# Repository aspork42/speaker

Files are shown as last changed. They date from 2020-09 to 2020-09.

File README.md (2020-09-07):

# Smart Speaker
Smart Speaker for DIY Home Automation 

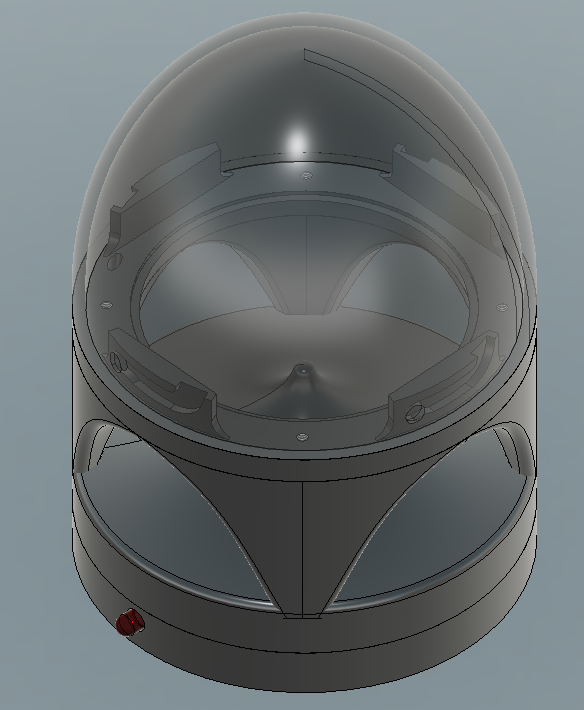
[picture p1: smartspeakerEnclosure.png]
Smart Speaker Enclosure


This is based on software by Mr DIY's "Notifier" project. I have modified it to include a status LED and created a PCB and enclosure for a 3" speaker.

This can be used to play a sound when doors are opened, faucets are left running, water is found flooding the basement or to play nursery rhymes in the kids room at night.

This uses a D1 Mini WIFI module, an Adafruit MAX 98357A I2S Audio DAC & amplifier, and a custom PCB.

Most of the base software is from Mr. DIY and all the write-ups can be found on his GitLab page: https://gitlab.com/MrDIYca/mrdiy-audio-notifier

STP files are located on Thingiverse: https://www.thingiverse.com/thing:4590242

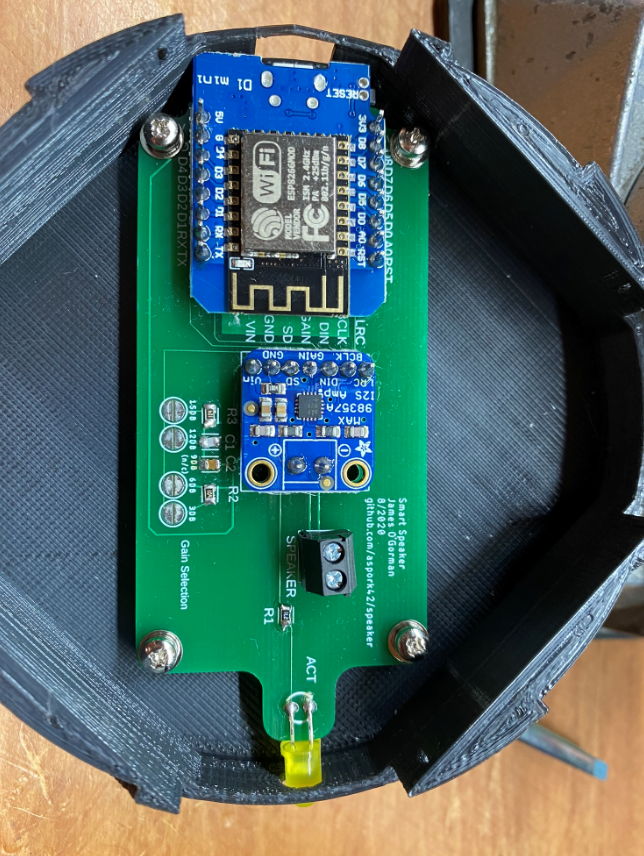
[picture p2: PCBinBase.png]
PCB mounted inside base unit


Finished product:
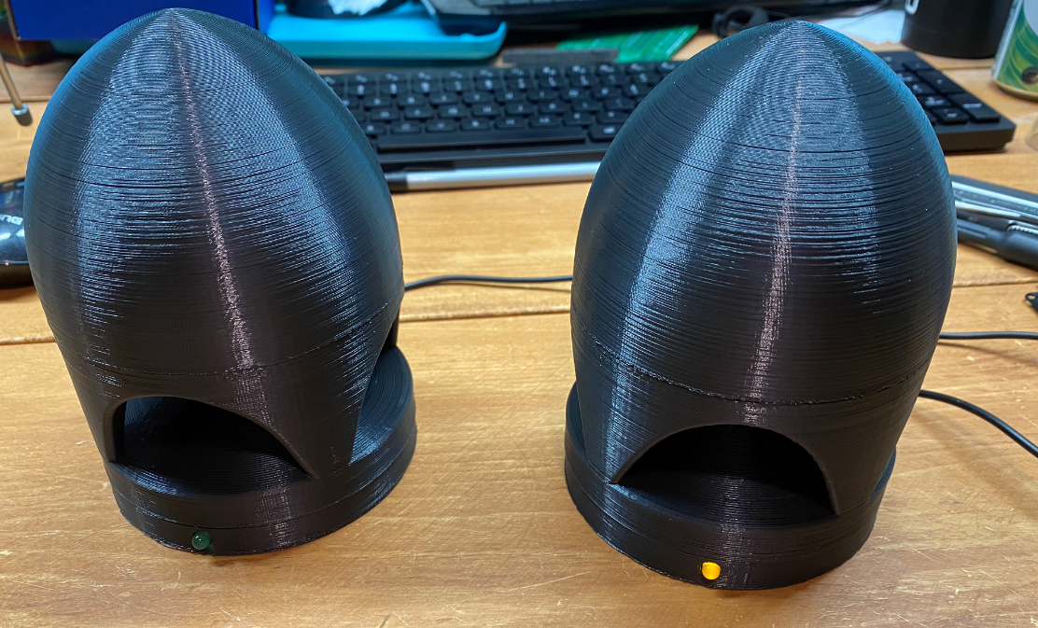
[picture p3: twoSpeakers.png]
Two finsihed units


Speaker:https://www.adafruit.com/product/1314

I2S DAC/Amplifier: https://www.adafruit.com/product/3006

PCB can be ordered from the Gerbers attached in the zip file.

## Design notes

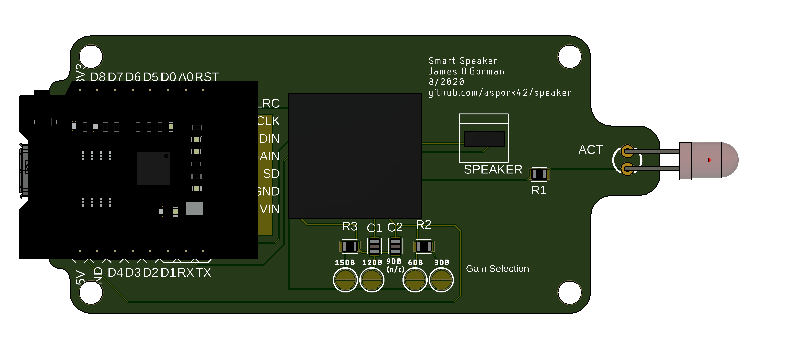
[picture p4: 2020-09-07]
PCB.png

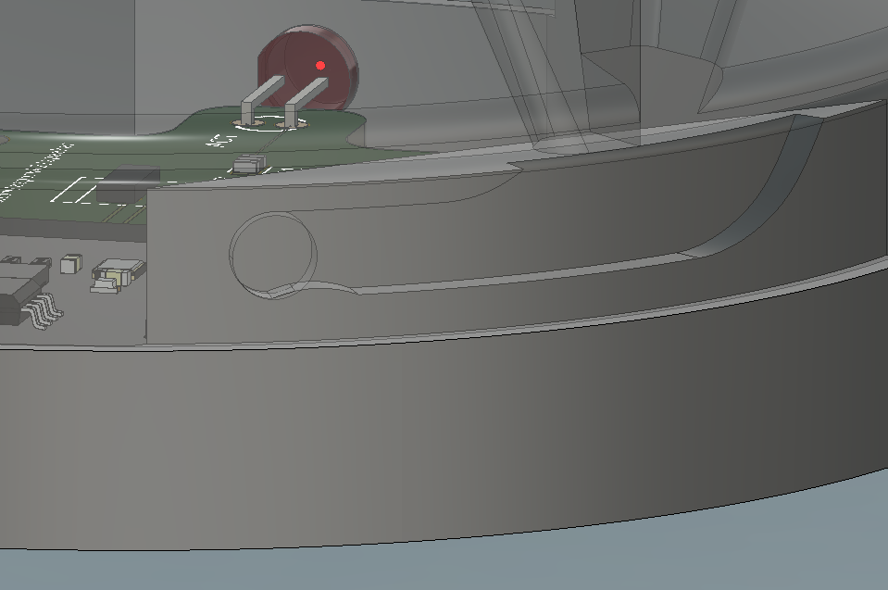
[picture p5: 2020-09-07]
CenterAndBaseInterlock.png

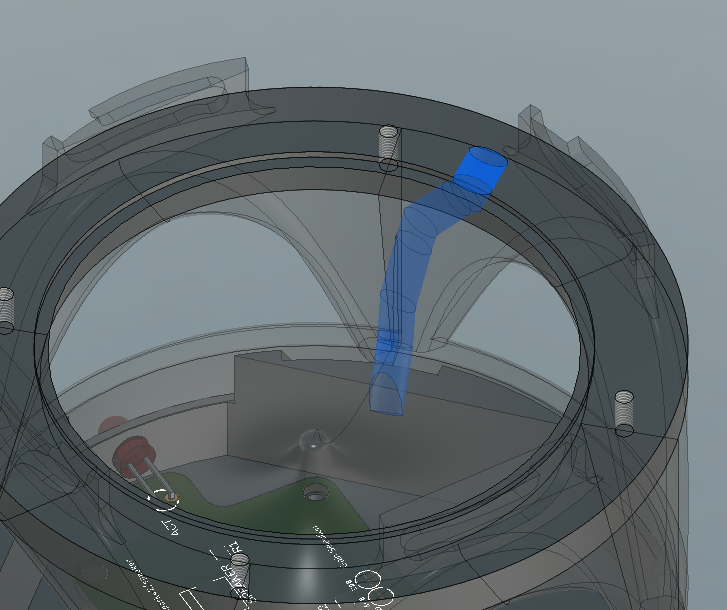
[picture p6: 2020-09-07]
WireChannel.png

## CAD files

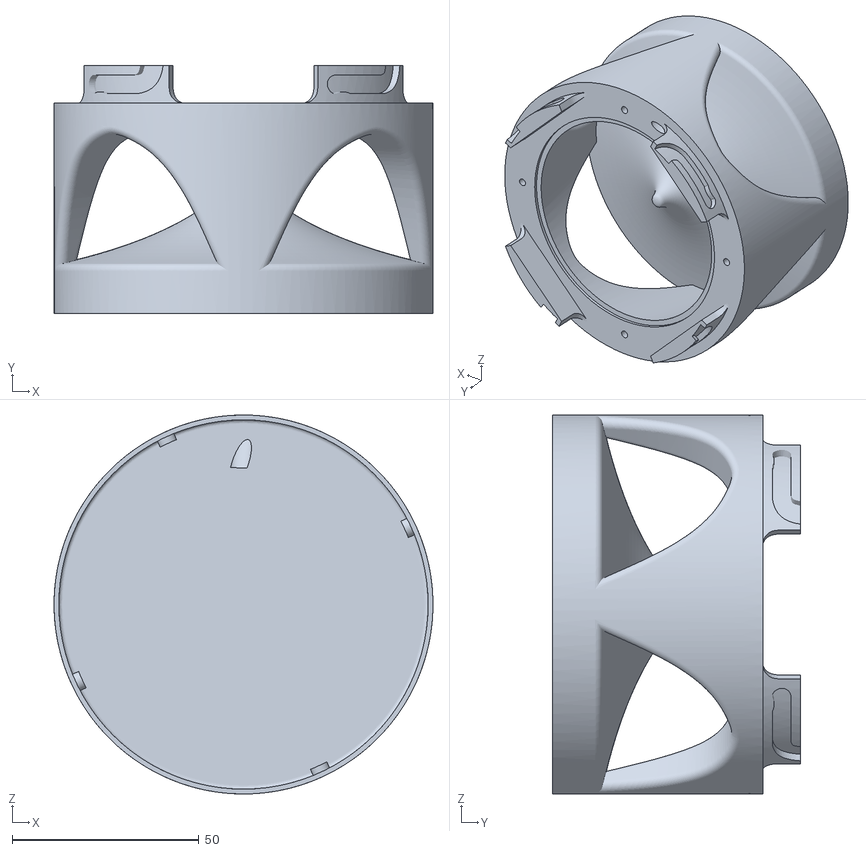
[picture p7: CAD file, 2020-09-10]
MainBody-1.stl
101.6 x 66.4 x 101.6

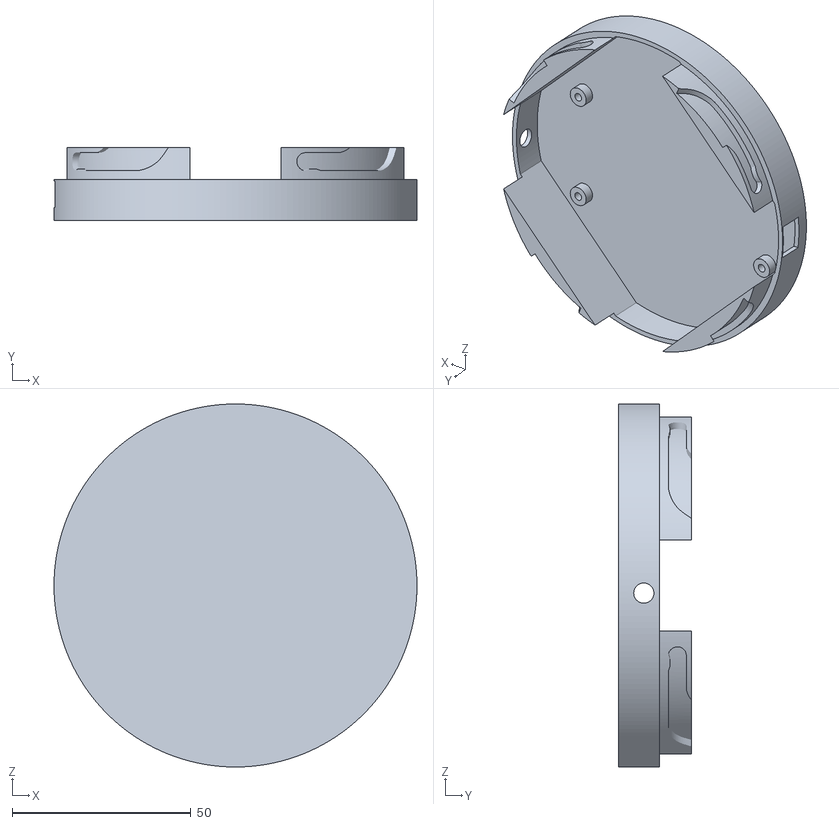
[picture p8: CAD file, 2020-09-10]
Base-1.stl
101.6 x 20.5 x 101.6

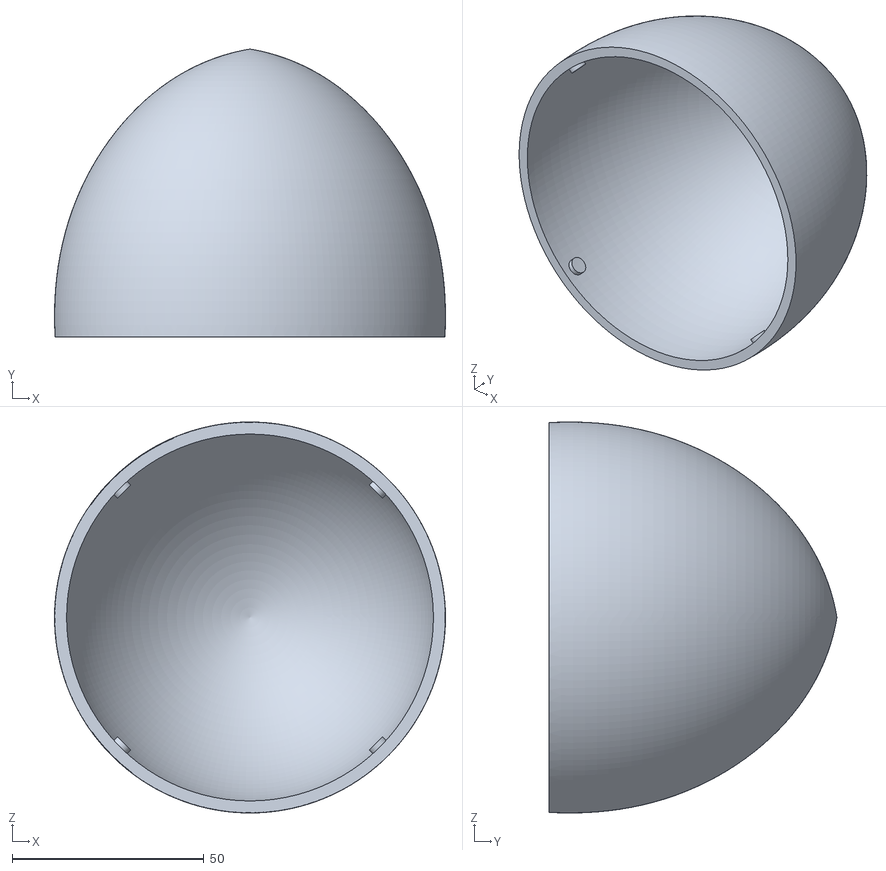
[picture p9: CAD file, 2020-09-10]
Top.stl
101.9 x 75.0 x 101.9

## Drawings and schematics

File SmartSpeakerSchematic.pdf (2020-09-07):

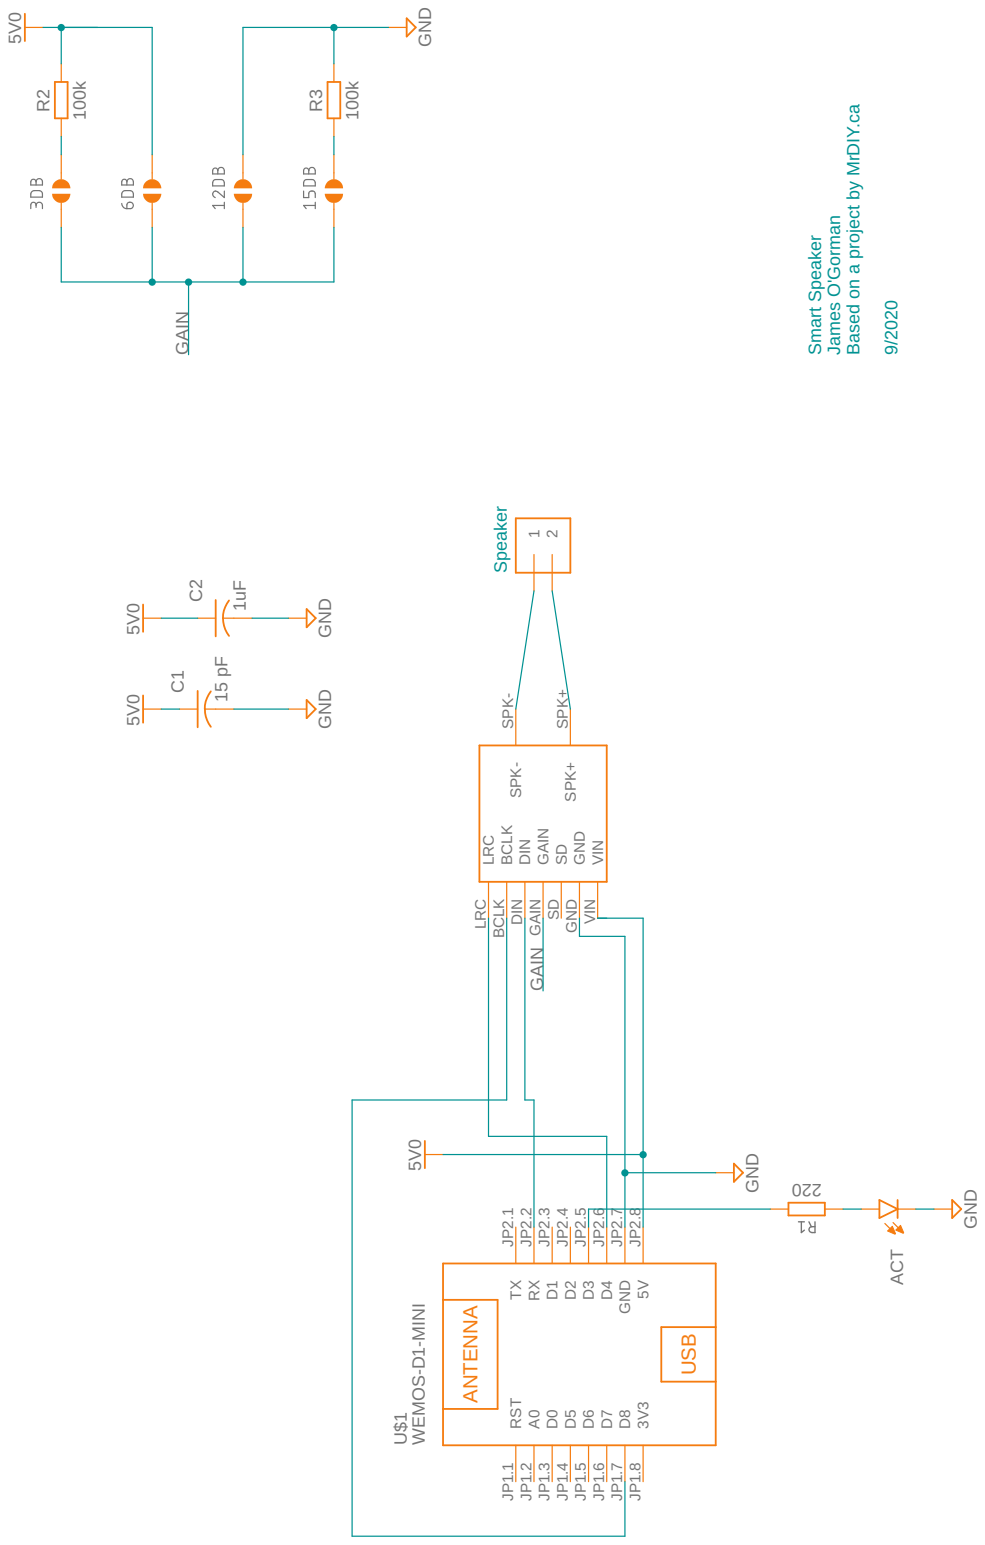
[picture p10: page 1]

WEMOS-D1-MINI GNDGN5VD 0 GND 5V0 5V0 GN1D5 pF 5V0 GN1DuF RST JP1.1 A0 JP1.2 D0 JP1.3 D5 JP1.4 D6 JP1.5 D7 JP1.6 D8 JP1.7 3V3 JP1.8 TX JP2.1 RX JP2.2 D1 JP2.3 D2 JP2.4 D3 JP2.5 D4 JP2.6 GND JP2.7 5V JP2.8 U$1 ACT 022 R2 100k R3 100k SPK- SPK- SPK+ SPK+ VIN VIN GND GND SD SD GAIN GAIN BCLK BCLK LRC LRC DIN DIN C1 12 C2 GAIN GAIN USB ANTENNA Speaker Smart Speaker James O'Gorman Based on a project by MrDIY.ca 9/2020

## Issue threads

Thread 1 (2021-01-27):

DAC Query

adamrhoades, 2021-01-27:
Love this project, perfect solution for offline alerts at my elderly mothers house.

I’m attempting to solve the popping issue and plan to try a  I2S DAC.

My question… I’m using an old set of amplified PC speakers as the output, would the adafruit MAX98357A still be a suitable DAC, or would an un-amplfied one such as the UDA1334A be a better fit for my use case?

Thanks in advance!

aspork42, 2021-01-27:
Technically you are correct. The component that I used includes an amplifier, so you could plug a speaker in directly to it. If you are using an external amp like an old set of PC speakers, then you can use the UDA1334A. That being said, you could just as well still use the project as posted and control the volume/gain via the solder jumpers on the PCB to run it down in amplification and then the PC speakers will still work just fine. If you're not using the PCB posted here, then i'd go the route you selected. You can use perfboard and solder the components. and I'm like >95% sure that it should work as-is.

adamrhoades, 2021-01-28:
Thank you so much, I'll order a UDA1334A and see how I get on. Will keep you posted!

adamrhoades, 2021-01-29:
Got the UDA1334A wired up and the esp8266_mrdiy_mqtt_local_notifier-I2S.bin flashed.

Partial Success, once configured it plays the guitar riff to indicate it has connected to the wifi and the MQTT.

The module returns pings and is accessible via the web interface, but it will not respond to MQTT messages.

Power cycling makes it forget the wifi settings and it goes into AP mode.

Any suggestions for me to troubleshoot?

aspork42, 2021-01-29:
Try to see if you can compile and upload from the Arduino IDE. I had the same problem with the original Mr DIY image until I did that. Otherwise check settings for erasing flash.

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

adamrhoades, 2021-02-03:
Thanks for getting back to me.

I complied it myself, erased the flash and uploaded and that has solved the issue of forgetting wifi.

The DAC seems to be working as it plays the guitar riff on connection. I assume that also means it has connected to the MQTT broker?

However it will still not respond to MQTT commands.

Any further thoughts?

aspork42, 2021-02-04:
Sorry for the troubles. It is probably related to posting to the correct MQTT Topic. The sound should only play if the device connects to the broker; so that part should be fine. I’ll post the topics i’m using to you in a little while when I get a second. Don’t forget that you can configure the topic individually for each device. I have 5, so each has its own sub-topic that it listens to. That’s why the documentation says "mqttFullTopic()/play"

It doesn’t mean to POST to mqttFullTopic/Play, it means that once you configure your topic like “MySpeaker” that you can then post to MySpeaker/play and it will respond.

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

aspork42, 2021-02-04:
This is my config website:
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

and I post to the full topic like this:
Notifier/Basement/say
Notifier/Basement/play
Notifier/Basement/tone
Notifier/Basement/stop
Notifier/Basement/volume

and get LWT from:
Notifier/Basement/LWT

aspork42, 2021-02-04:
What part of the world are you in?

adamrhoades, 2021-02-10:
So sorry for the late response... crazy week.

I'm based in Lincoln, England... you?

Adding the prefix of Notifier to my existing topic solved the problem
I'm now using: Notifier/Speakers

Initially I had problems with inconsistent playback quality; popping, missing portions etc but I reduced the MP3 files down to mono with a low variable bitrate of between 40-85kbps and it sounds great now!

I also experimented with copying the google tts cache mp3s and using those... they sound great too!

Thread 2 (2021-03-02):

Board Conversion

creativewitty, 2021-03-02:
Hey James, MrDiy directed to me to this fork and this looks great.
I know a bit about electronics but not as much..

Is there a way to convert the board to components where normal non smd components are required.
and say if i wanted to add a poteniometer for volume where would that be implemented?

aspork42, 2021-03-02:
Hello,

Version 2 of the PCB which is on GitHub has been converted with 'dual pattern' so you can use through-hole resistors (OR surface mount). For the other components like the capacitors, you don't actually need to use them so you can leave unpopulated. They pre-set the amplification on the DAC.

If you wanted to add an analog volume knob, you would use a potentiometer. Hook one side to 3.3v, the opposite side to GND, and the center pin (which is the analog outputs) into the "A0" pin which is the analog. You would need to update the code to read the pin, look for a change in the analog value, and update the volume setting.

Reading an analog pin on the arduino (This will basically follow the Aruduino reference using pin A0)
https://www.arduino.cc/reference/en/language/functions/analog-io/analogread/

More info on reading an analog pin, along with diagram (on Arduino Uno) on how to wire it).
https://microcontrollerslab.com/analogread-arduino-example/

You would probably do something like the Map() function to map the 0-1028 analog value into a 0-100 for the volume and that will constrain the values to 0-100, and scaled accordingly.

creativewitty, 2021-03-03:
Wow This is great and thank you for your guidance, I should be getting my DACs in the mail today so will start to tinker with em and update my progress.

And For volume I realized MrDiy's code has volume commands too, so maybe I can just use something to control it via mqtt than hardware. but I will still try to achieve the volume option with the analog input. And will post my progress.

Cheers Aktion!

aspork42, 2021-03-03:
Sorry -  I guess I assumed you wanted to override the volume coming from MQTT. I've found that I don't change the volume on these. I run OpenHAB and use a rule to set the volume there on each device when they come online (by watching the LWT topic). I made five of these and put them around my house and LOVE having them.

So you could do the analog with a knob, or you could also do it with two buttons - UP and DOWN - which would be easier to code. When the button is pressed, you just run the volume up by 10 or down by 10.

creativewitty, 2021-03-03:
No I did, i did initially think of overriding that but since I will be using the speakers for alarm too i figured might not be a good idea to have a volume control on it :)

I am using home assistant and it's super easy with the mqtt integration so I will setup something for volume control from within.

I tested the system with a Drok amp and D1 chip and it works like a charm.
now time to optimize the setup using the Dac.
!

[first try](https://user-images.githubusercontent.com/1167235/109852438-c58cbf80-7c22-11eb-9cbd-760fd9f684a6.jpeg)

https://user-images.githubusercontent.com/1167235/109852443-c7568300-7c22-11eb-8278-7aabfb7b2606.mp4

aspork42, 2021-03-03:
Nice work! You could have the knob just override the current MQTT value, then have a rule reset the volume in the morning before the alarm goes off.

creativewitty, 2021-03-03:
Thanks, also wanted to ask you before you used the dac as a solution did you think of anything else to remove the pooping of clicking sound?

creativewitty, 2021-03-04:
Does this look right to you? I decided to go for dip switches for gain points.

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

aspork42, 2021-03-06:
I did play with it a little to try resolving the Pop, and finally just spent a few bucks on the DAC. The problem is using the Rx pin. The D1 mini writes it LOW (0 volts) when not playing audio, then writes it HIGH (3.3V) before playback starts. This is the cause for the pop. The analog audio level is millivolts peak to peak, so a 3+V change is a pretty large swing.

creativewitty, 2021-03-07:
Yeah I found the same info on the Interwebs :) But again thank you for taking out time to helping me, Your schematic was really helpful for me. I designed my first pcb. It is just a diff design with dip switches and thru mount resistor slot. very excited.

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

aspork42, 2021-03-07:
If you haven't ordered you PCB yet, don't forget to add mounting holes. Nice work on your first board!

creativewitty, 2021-03-07:
Thank you!! and yeah I left them out on purpose for this one.
But I might make another to put it our for people and there i will have the mounting holes.

I might even make a video about mqtt and home assistant where i will include this so will definitely leave your link there!

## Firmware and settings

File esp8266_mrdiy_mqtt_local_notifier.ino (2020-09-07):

/*  ==============================================================================================================
    MrDIY is an locally-controlled over MQTT, internet-independent media notifier that can play MP3s, stream
    icecast radios, read text and play RTTTL ringtones without any external components.

    Connect your audio jack to Rx and GND - an external amplifier if required. You can build a simple amp
    with a single 1kΩ resistor and an NPN 2N3904 transistor, like this:


                                        2N3904 (NPN)
                                       +---------+
                                       |         |     +--|
                                       | E  B  C |    / S |
                                       +-|--|--|-+    | P |
                                         |  |  +------+ E |
                                         |  |         | A |
           ESP8266-GND ------------------+  |  +------+ K |
                                            |  |      | E |
           ESP8266-I2SOUT (Rx) -----/\/\/\--+  |      \ R |
                                     1kΩ       |       +--|
           USB 5V -----------------------------+


    Commands, to:

     - Play MP3              MQTT topic: "mqttFullTopic()/play"
                             MQTT load: http://url-to-the-mp3-file/file.mp3

     - Play Icecast Stream   MQTT topic: "mqttFullTopic()/stream"
                             MQTT load: http://url-to-the-icecast-stream/file.mp3, example: http://22203.live.streamtheworld.com/WHTAFM.mp3

     - Play Ringtone         MQTT topic: "mqttFullTopic()/tone"
                             MQTT load: RTTTL formated text, example: Soap:d=8,o=5,b=125:g,a,c6,p,a,4c6,4p,a,g,e,c,4p,4g,a

     - Say Text              MQTT topic: "mqttFullTopic()/say"
                             MQTT load: Text to be read, example: Hello There. How. Are. You?

     - Change Volume         MQTT topic: "mqttFullTopic()/volume"
                             MQTT load: a double between 0.00 and 1.00, example: 0.7

     - Stop Playing         MQTT topic: "mqttFullTopic()/stop"

     To get status:

     - The notifier sends status update on this MQTT topic: "mqttFullTopic()/status"

                  "playing"       either paying an mp3, streaming, playing a ringtone or saying a text
                  "idle"          waiting for a command
                  "error"         error when receiving a command: example: MP3 file URL can't be loaded
                  "connected"     device just connected to MQTT server

     - The notifier plays a 2 second audio clip when it is first booted and connected to Wifi & MQTT


    To Upload to Wesmo D1 Mini:

     - Set CPU Frequency to 160MHz
     - Set IwIP to V2 Higher Bandwidth
     - Update the SSID info
     - Connect Rx to an AMP

    Dependencies:

     - ESP8266          https://github.com/esp8266/Arduino
     - ESP8266Audio     https://github.com/earlephilhower/ESP8266Audio
     - ESP8266SAM       https://github.com/earlephilhower/ESP8266SAM
     - IotWebConf       https://github.com/prampec/IotWebConf
     - PubSubClient     https://github.com/knolleary/pubsubclient


    Many thanks to all the authors and contributors to the above libraries - you have done an amazing job!

    For more info visit me at MrDIY.ca and find the Notifier Video on my YouTube channel:
    https://youtu.be/SPa9SMyPU58

  ============================================================================================================== */

//#define DEBUG_FLAG

#define USE_I2S //uncomment to use I2S DAC instead of Serial Rx pin.

#include "Arduino.h"
#include "boot_sound.h"
#include "ESP8266WiFi.h"
#include "PubSubClient.h"
#include "AudioFileSourceHTTPStream.h"
#include "AudioFileSourceICYStream.h"
#include "AudioFileSourcePROGMEM.h"
#include "AudioFileSourceBuffer.h"
#include "AudioGeneratorMP3.h"
#include "AudioGeneratorWAV.h"
#include "AudioGeneratorRTTTL.h"

#ifdef USE_I2S
  #include "AudioOutputI2S.h"
#else
  #include "AudioOutputI2SNoDAC.h"
#endif

#include "ESP8266SAM.h"
#include "IotWebConf.h"

AudioGeneratorMP3         *mp3 = NULL;
AudioGeneratorWAV         *wav = NULL;
AudioGeneratorRTTTL       *rtttl = NULL;
AudioFileSourceHTTPStream *file_http = NULL;
AudioFileSourcePROGMEM    *file_progmem = NULL;
AudioFileSourceICYStream *file_icy = NULL;
AudioFileSourceBuffer     *buff = NULL;

#ifdef USE_I2S
  AudioOutputI2S       *out = NULL;
#else
  AudioOutputI2SNoDAC       *out = NULL;
#endif

WiFiClient                wifiClient;
PubSubClient              mqttClient(wifiClient);
#define  port             1883
#define  MQTT_MSG_SIZE    256

#define LED_Pin 0 // for the external LED pin.

// AudioRelated ---------------------------
float volume_level              = 0.8;
String playing_status;
const int preallocateBufferSize = 2048;
void *preallocateBuffer         = NULL;
byte i;

//Get chip ID to append to ThingName to make unique
#ifdef ESP8266
String ChipId = String(ESP.getChipId(), HEX);
#elif ESP32
String ChipId = String((uint32_t)ESP.getEfuseMac(), HEX);
#endif

// WifiManager -----------------------------
String thingName = String("MrDIY Notifier - ") + ChipId; 
#define wifiInitialApPassword "mrdiy.ca"
char mqttServer[16];
char mqttUserName[32];
char mqttUserPassword[32];
char mqttTopicPrefix[32];
char mqttTopic[MQTT_MSG_SIZE];
DNSServer             dnsServer;
WebServer             server(80);
IotWebConf            iotWebConf(thingName.c_str(), &dnsServer, &server, wifiInitialApPassword, "JamesOGorman");
IotWebConfParameter   mqttServerParam = IotWebConfParameter("MQTT server", "mqttServer", mqttServer, sizeof(mqttServer) );
IotWebConfParameter   mqttUserNameParam = IotWebConfParameter("MQTT username", "mqttUser", mqttUserName, sizeof(mqttUserName));
IotWebConfParameter   mqttUserPasswordParam = IotWebConfParameter("MQTT password", "mqttPass", mqttUserPassword, sizeof(mqttUserPassword), "password");
IotWebConfParameter   mqttTopicParam = IotWebConfParameter("MQTT Topic", "mqttTopic", mqttTopicPrefix, sizeof(mqttTopicPrefix));

//Last Will and Testament (LWT)
byte willQoS = 0;
char* willTopic = "LWT";
const char* willMessage ="Offline";
boolean willRetain = false;

/* ################################## Setup ############################################# */

void setup() {
  pinMode(LED_Pin, OUTPUT); // LED pin
  analogWrite(LED_Pin, 100);

#ifdef DEBUG_FLAG
  Serial.begin(115200);
#endif
  iotWebConf.addParameter(&mqttServerParam);
  iotWebConf.addParameter(&mqttUserNameParam);
  iotWebConf.addParameter(&mqttUserPasswordParam);
  iotWebConf.addParameter(&mqttTopicParam);
  iotWebConf.setWifiConnectionCallback(&wifiConnected);
  iotWebConf.setFormValidator(&formValidator);
  iotWebConf.setStatusPin(LED_BUILTIN);
  iotWebConf.skipApStartup();

  boolean validConfig = iotWebConf.init();
  if (!validConfig)
  {
    mqttServer[0] = '\0';
    mqttUserName[0] = '\0';
    mqttUserPassword[0] = '\0';
  }

  server.on("/", [] { iotWebConf.handleConfig(); });
  server.onNotFound([] {  iotWebConf.handleNotFound();  });
#ifdef USE_I2S
  out = new AudioOutputI2S();
  Serial.println("Using I2S output");
#else
  out = new AudioOutputI2SNoDAC(); 
  Serial.println("Using No DAC - using Serial port Rx pin");
#endif
  out->SetGain(volume_level);
}

/* ##################################### Loop ############################################# */

void loop() {

  mqttReconnect();
  mqttClient.loop();
  // give processor priority to audio
  if (!mp3) iotWebConf.doLoop();
  if (mp3   && !mp3->loop())    stopPlaying();
  if (wav   && !wav->loop())    stopPlaying();
  if (rtttl && !rtttl->loop())  stopPlaying();

#ifdef DEBUG_FLAG
  if (mp3 && mp3->isRunning()) {
    static int unsigned long lastms = 0;
    if (millis() - lastms > 1000) {
      lastms = millis();
      Serial.print(F("Free: "));
      Serial.print(ESP.getFreeHeap(), DEC);
      Serial.print(F("  ("));
      Serial.print( ESP.getFreeHeap() - ESP.getMaxFreeBlockSize(), DEC);
      Serial.print(F(" lost)"));
      Serial.print(F("  Fragmentation: "));
      Serial.print(ESP.getHeapFragmentation(), DEC);
      Serial.print(F("%"));
      if ( ESP.getHeapFragmentation() > 40) Serial.print(F("  ----------- "));
      Serial.println();
    }
  }
#endif
}

/* ############################### Audio ############################################ */

void playBootSound() {

  file_progmem = new AudioFileSourcePROGMEM(boot_sound, sizeof(boot_sound));
  wav = new AudioGeneratorWAV();
  wav->begin(file_progmem, out);
}

void stopPlaying() {
  analogWrite(LED_Pin, 255); //Turn LED back to full brightness

  if (mp3) {
#ifdef DEBUG_FLAG
    Serial.print(F("...#"));
    Serial.println(F("Interrupted!"));
    Serial.println();
#endif
    mp3->stop();
    delete mp3;
    mp3 = NULL;
  }
  if (wav) {
    wav->stop();
    delete wav;
    wav = NULL;
  }
  if (rtttl) {
    rtttl->stop();
    delete rtttl;
    rtttl = NULL;
  }
  if (buff) {
    buff->close();
    delete buff;
    buff = NULL;
  }
  if (file_http) {
    file_http->close();
    delete file_http;
    file_http = NULL;
  }
  if (file_progmem) {
    file_progmem->close();
    delete file_progmem;
    file_progmem = NULL;
  }
  if (file_icy) {
    file_icy->close();
    delete file_icy;
    file_icy = NULL;
  }
  broadcastStatus("status", "idle");
}

/* ################################## MQTT ############################################### */

void onMqttMessage(char* topic, byte* payload, unsigned int length)  {

  char newMsg[MQTT_MSG_SIZE];

  if (length > 0) {
    memset(newMsg, '\0' , sizeof(newMsg));
    memcpy(newMsg, payload, length);
#ifdef DEBUG_FLAG
    Serial.println();
    Serial.print(F("Requested ["));
    Serial.print(topic);
    Serial.print(F("] "));
    Serial.println(newMsg);
#endif
    // got a new URL to play ------------------------------------------------
    if ( !strcmp(topic, mqttFullTopic("play") ) ) {
      stopPlaying();
      file_http = new AudioFileSourceHTTPStream();
      if ( file_http->open(newMsg)) {
        broadcastStatus("status", "playing");
        analogWrite(LED_Pin, 100); // Dim LED while playing
        buff = new AudioFileSourceBuffer(file_http, preallocateBuffer, preallocateBufferSize);
        mp3 = new AudioGeneratorMP3();
        mp3->begin(buff, out);
      } else {
        stopPlaying();
        broadcastStatus("status", "error");
        broadcastStatus("status", "idle");
      }
    }

    // got a new URL to play ------------------------------------------------
    if ( !strcmp(topic, mqttFullTopic("stream"))) {
      stopPlaying();
      file_icy = new AudioFileSourceICYStream();
      if ( file_icy->open(newMsg)) {
        broadcastStatus("status", "playing");
        analogWrite(LED_Pin, 100); // Dim LED while playing
        buff = new AudioFileSourceBuffer(file_icy, preallocateBuffer, preallocateBufferSize);
        mp3 = new AudioGeneratorMP3();
        mp3->begin(buff, out);
      } else {
        stopPlaying();
        broadcastStatus("status", "error");
        broadcastStatus("status", "idle");
      }
    }

    // got a tone request --------------------------------------------------
    if ( !strcmp(topic, mqttFullTopic("tone") ) ) {
      stopPlaying();
      broadcastStatus("status", "playing");
      analogWrite(LED_Pin, 100); // Dim LED while playing
      file_progmem = new AudioFileSourcePROGMEM( newMsg, sizeof(newMsg) );
      rtttl = new AudioGeneratorRTTTL();
      rtttl->begin(file_progmem, out);
      broadcastStatus("status", "idle");
    }

    //got a TTS request ----------------------------------------------------
    if ( !strcmp(topic, mqttFullTopic("say"))) {
      stopPlaying();
      broadcastStatus("status", "playing");
      analogWrite(LED_Pin, 100); // Dim LED while playing
      ESP8266SAM *sam = new ESP8266SAM;
      sam->Say(out, newMsg);
      delete sam;
      stopPlaying();
      broadcastStatus("status", "idle");
    }

    // got a volume request, expecting double [0.0,1.0] ---------------------
    if ( !strcmp(topic, mqttFullTopic("volume"))) {
      volume_level = atof(newMsg);
      if ( volume_level < 0.0 ) volume_level = 0;
      if ( volume_level > 1.0 ) volume_level = 0.7;
      out->SetGain(volume_level);
    }

    // got a stop request  --------------------------------------------------
    if ( !strcmp(topic, mqttFullTopic("stop"))) {
      stopPlaying();
    }
  }
}

void broadcastStatus(char topic[], String msg) {

  if ( playing_status != msg) {
    char charBuf[msg.length() + 1];
    msg.toCharArray(charBuf, msg.length() + 1);
    mqttClient.publish(mqttFullTopic(topic), charBuf);
    playing_status = msg;
#ifdef DEBUG_FLAG
    Serial.println();
    Serial.print("status: ");
    Serial.println(msg);
#endif
  }
}


void mqttReconnect() {

  if (!mqttClient.connected()) {
    analogWrite(LED_Pin, 100); //turn LED low if not connected 
    
    if (mqttClient.connect(thingName.c_str(), mqttUserName, mqttUserPassword, mqttFullTopic(willTopic), willQoS, willRetain, willMessage)) {
      broadcastStatus("status", "connected");
      mqttClient.subscribe(mqttFullTopic("play"));
      mqttClient.subscribe(mqttFullTopic("stream"));
      mqttClient.subscribe(mqttFullTopic("tone"));
      mqttClient.subscribe(mqttFullTopic("say"));
      mqttClient.subscribe(mqttFullTopic("stop"));
      mqttClient.subscribe(mqttFullTopic("volume"));
#ifdef DEBUG_FLAG
      Serial.println();
      Serial.print(F("Connected to MQTT: "));
      Serial.println(F("mrdiynotifier"));
#endif
      broadcastStatus(willTopic, "Online");
      broadcastStatus("ThingName", thingName.c_str());
      broadcastStatus("IPAddress", WiFi.localIP().toString()); 
      broadcastStatus("status", "idle");
      analogWrite(LED_Pin, 255); // Turn LED HIGH once connected to MQTT
    }
  }
}
/* ############################ WifiManager ############################################# */

void wifiConnected() {

#ifdef DEBUG_FLAG
  Serial.println();
  Serial.println(F("=================================================================="));
  Serial.println(F("  MrDIY Notifier"));
  Serial.println(F("=================================================================="));
  Serial.println();
  Serial.print(F("Connected to Wifi ["));
  Serial.print(WiFi.localIP());
  Serial.println(F("]"));
#endif
  playBootSound();
  mqttClient.setServer(mqttServer, port);
  mqttClient.setCallback(onMqttMessage);
  mqttClient.setBufferSize(MQTT_MSG_SIZE);
  mqttReconnect();
}

boolean formValidator() {

  boolean valid = true;
  int l = server.arg(mqttServerParam.getId()).length();
  if (l == 0) {
    mqttServerParam.errorMessage = "Please provide the MQTT server address";
    valid = false;
  }
  return valid;
}

char* mqttFullTopic(char action[]) {
  strcpy (mqttTopic, mqttTopicPrefix);
  strcat (mqttTopic, "/");
  strcat (mqttTopic, action);
  return mqttTopic;
}

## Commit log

2020-09-07 Gerber files
    These are the gerber files for the PCB using 0805 resistors.
2020-09-07 Adding images, schematic, and base arduino code
    Arduino code is almost entirely done by Mr. DIY. I have modified to use I2S DAC/Amplifier and am adding an LED.
    https://gitlab.com/MrDIYca/mrdiy-audio-notifier
2020-09-10 Dual pattern resistors
    Added through-hole resistors onto PCB. Only installing one set of resistors is required.
2020-09-10 Including STL files
    Added STL files for manufacturing of enclosure (3D Printing)
    [Base-1.stl, MainBody-1.stl, Top.stl]
2020-10-12 Add .stp of PCB
    Uploading 3d Step file of populated PCB with D1Mini and LED.
